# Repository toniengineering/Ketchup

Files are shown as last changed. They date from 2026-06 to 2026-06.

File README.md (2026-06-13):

So this is KETCHUP based on a ketchup bottle but with a little twist. So I like ketchup and with the pcb board I was inspired to use it in the project. With this I made the pcb base look like a ketchup bottle. The LEDs on it form a cap at the top then will blink in a little wave loop under it. It starts at ketchup, then loop, then the word finish where the last LED is.





BOM:

|Name |Purpose|Quantity|Total Cost (USD)|Link |Distributor|
|---|---|---|---|---|---|
|Ketchup|my pcb |5 |2.00 |https://cart.jlcpcb.com/shopcart/cart/|JLCPCB |

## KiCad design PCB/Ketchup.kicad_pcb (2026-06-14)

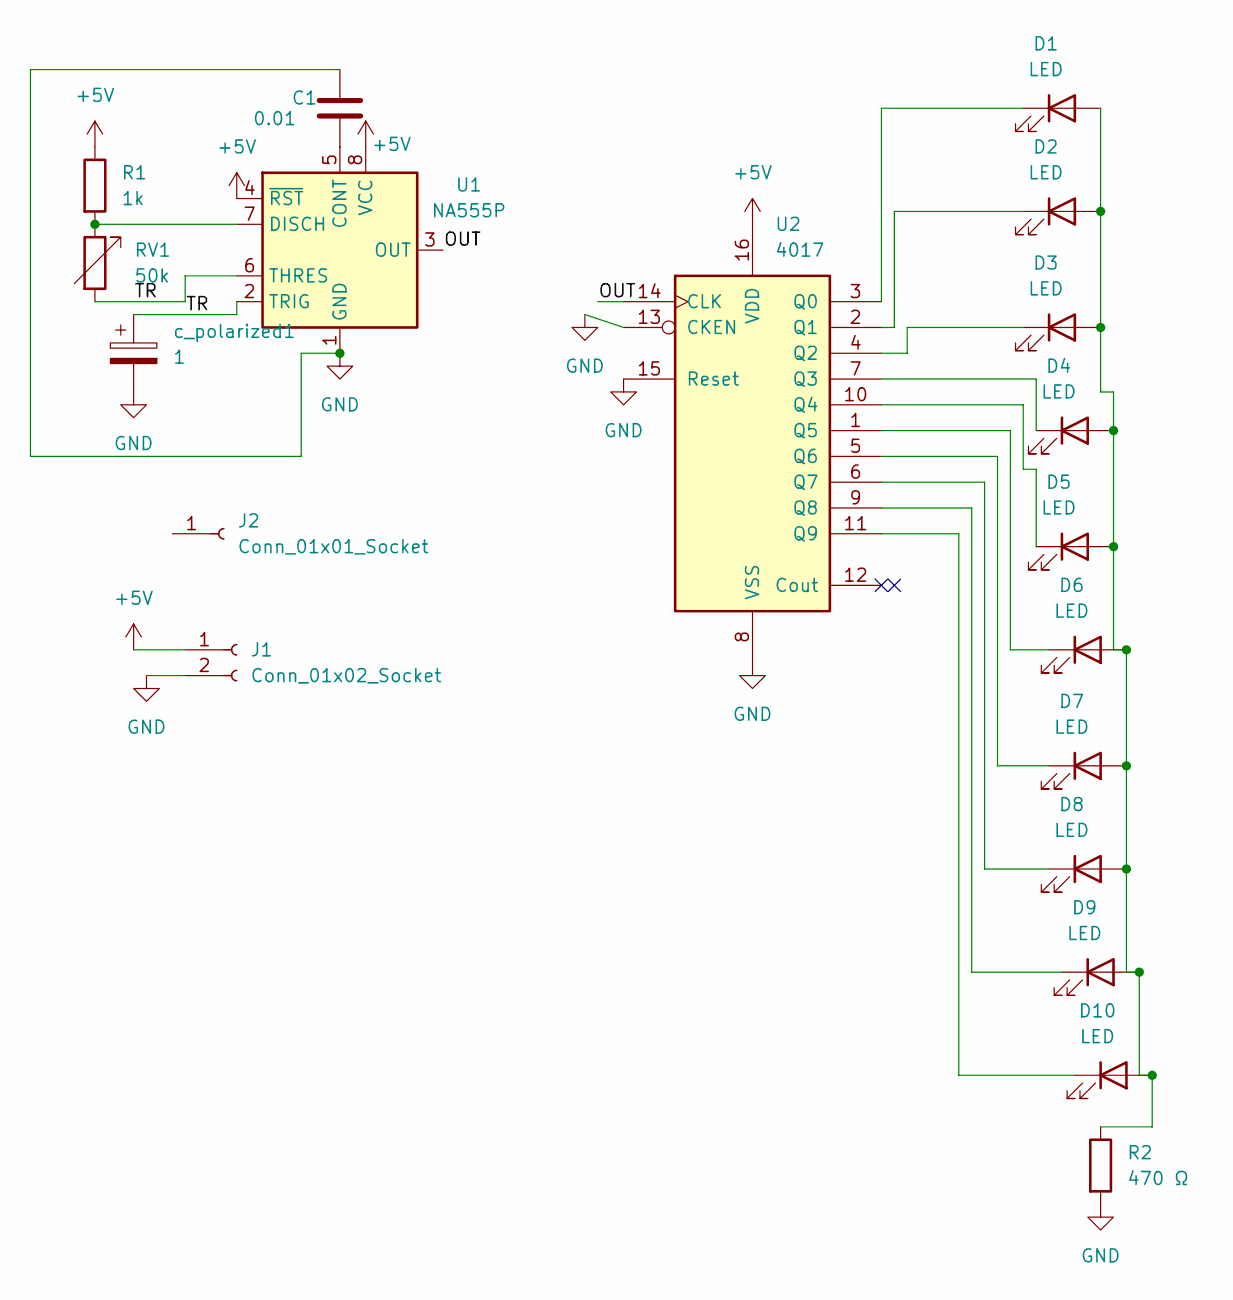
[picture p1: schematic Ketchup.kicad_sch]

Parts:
C1: 0.01; CP_Radial_D5.0mm_P2.00mm
D1, D2, D3, D4, D5, D6, D7, D8, D9, D10: LED; LED_D3.0mm
J1: Conn_01x02_Socket; PinHeader_1x02_P2.54mm_Vertical
J2: Conn_01x01_Socket; PinHeader_1x02_P2.54mm_Vertical
R1: 1k; R_Axial_DIN0207_L6.3mm_D2.5mm_P7.62mm_Horizontal
R2: 470 Ω; R_Axial_DIN0207_L6.3mm_D2.5mm_P7.62mm_Horizontal
RV1: 50k; Potentiometer_Vishay_T93YA_Vertical
U1: NA555P; DIP-8_W7.62mm
U2: 4017; N16
c_polarized1: 1; C_Disc_D7.5mm_W2.5mm_P5.00mm

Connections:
+5V: J1.1, R1.1, U1.4 (~RST), U1.8 (VCC), U2.16 (VDD)
/OUT: U1.3 (OUT), U2.14 (CLK)
/TR: RV1.2, U1.2 (TRIG), U1.6 (THRES), c_polarized1.1
GND: C1.1, J1.2, R2.2, U1.1 (GND), U2.8 (VSS), U2.13 (CKEN), U2.15 (Reset), c_polarized1.2
unnamed: D1.2 (A), D2.2 (A), D3.2 (A), D4.2 (A), D5.2 (A), D6.2 (A), D7.2 (A), D8.2 (A), D9.2 (A), D10.2 (A), R2.1
unnamed: D1.1 (K), U2.3 (Q0)
unnamed: D2.1 (K), U2.2 (Q1)
unnamed: D3.1 (K), U2.4 (Q2)
unnamed: D4.1 (K), U2.7 (Q3)
unnamed: D5.1 (K), U2.10 (Q4)
unnamed: D6.1 (K), U2.1 (Q5)
unnamed: D7.1 (K), U2.5 (Q6)
unnamed: D8.1 (K), U2.6 (Q7)
unnamed: D9.1 (K), U2.9 (Q8)
unnamed: D10.1 (K), U2.11 (Q9)
unnamed: C1.2, U1.5 (CONT)
unnamed: R1.2, RV1.1, U1.7 (DISCH)

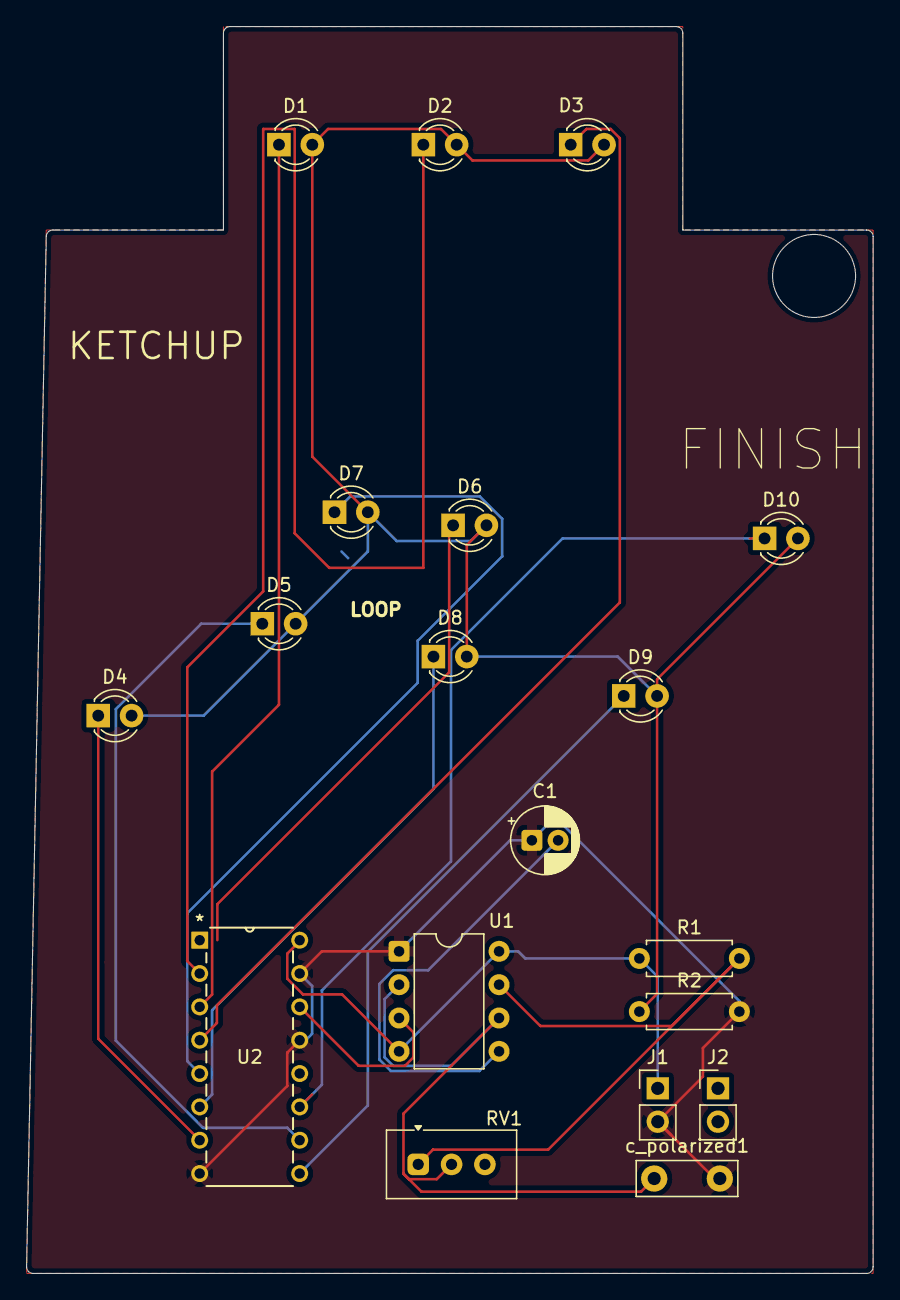
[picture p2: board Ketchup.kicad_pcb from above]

Board: 2 copper layers, 64.5 x 95.0 mm, 19 parts (0 on the bottom side), 17 nets.

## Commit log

2026-06-13 Create BOM
2026-06-13 Add BOM section to README
    Added BOM section with details for components.
